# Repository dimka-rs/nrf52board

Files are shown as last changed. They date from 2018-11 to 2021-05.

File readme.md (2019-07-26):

# NRF52 + LoRa dev board

## Known issues
- Q1 footprint does not match any fets I have

## Components
- [NRF52 module E73-2G4M04S](https://www.aliexpress.com/item/32820692238.html) 
- [LoRa module RFM95W](https://www.aliexpress.com/item/32811523237.html)
- USB-UART CP2102
- LDO LP5907MFX-3.3
- LiPo charger MCP73831-2-OT

[See board pinout](pinout.md)

Board images:

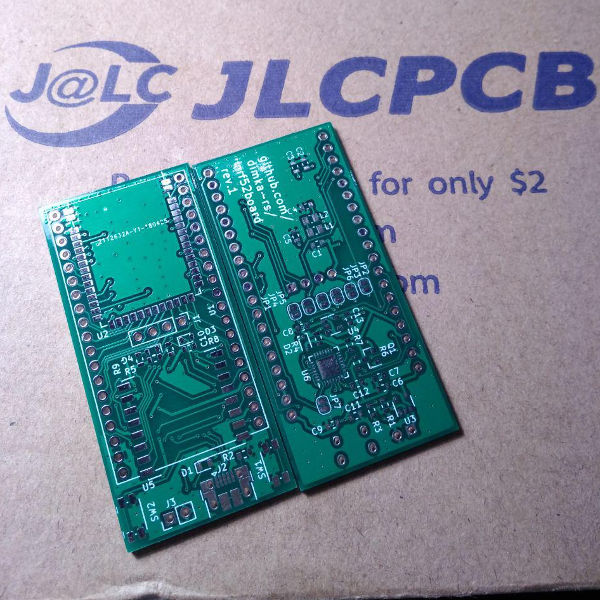
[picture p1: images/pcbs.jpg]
PCB Image

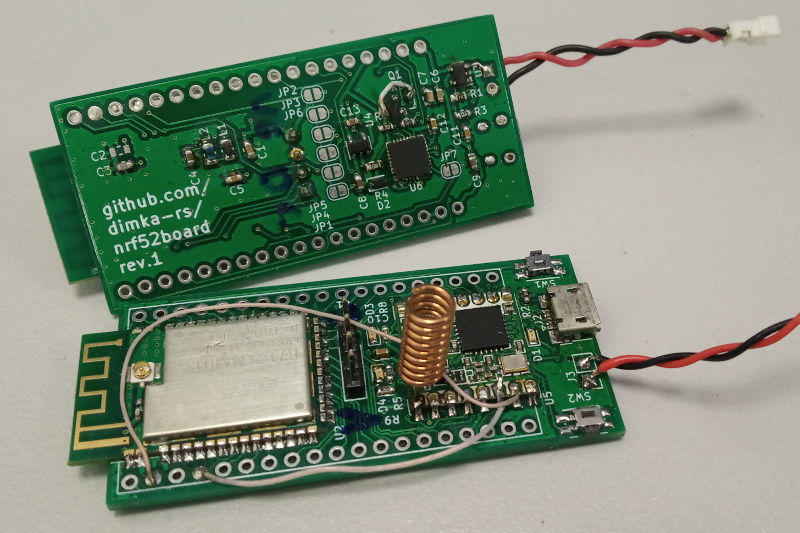
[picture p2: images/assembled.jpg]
Assembled boards


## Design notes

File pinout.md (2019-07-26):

# Board pinout

See tables below

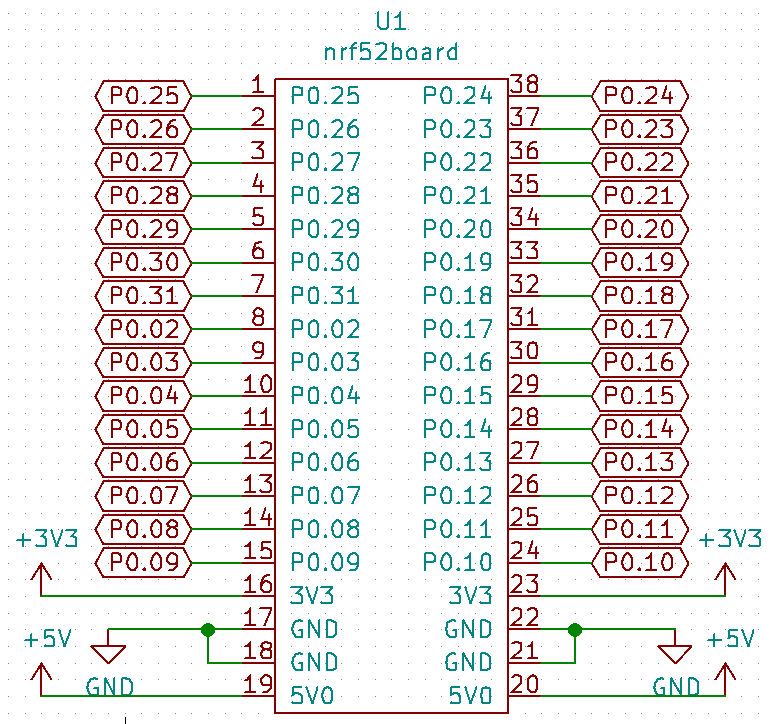
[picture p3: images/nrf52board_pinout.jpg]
pinout 1

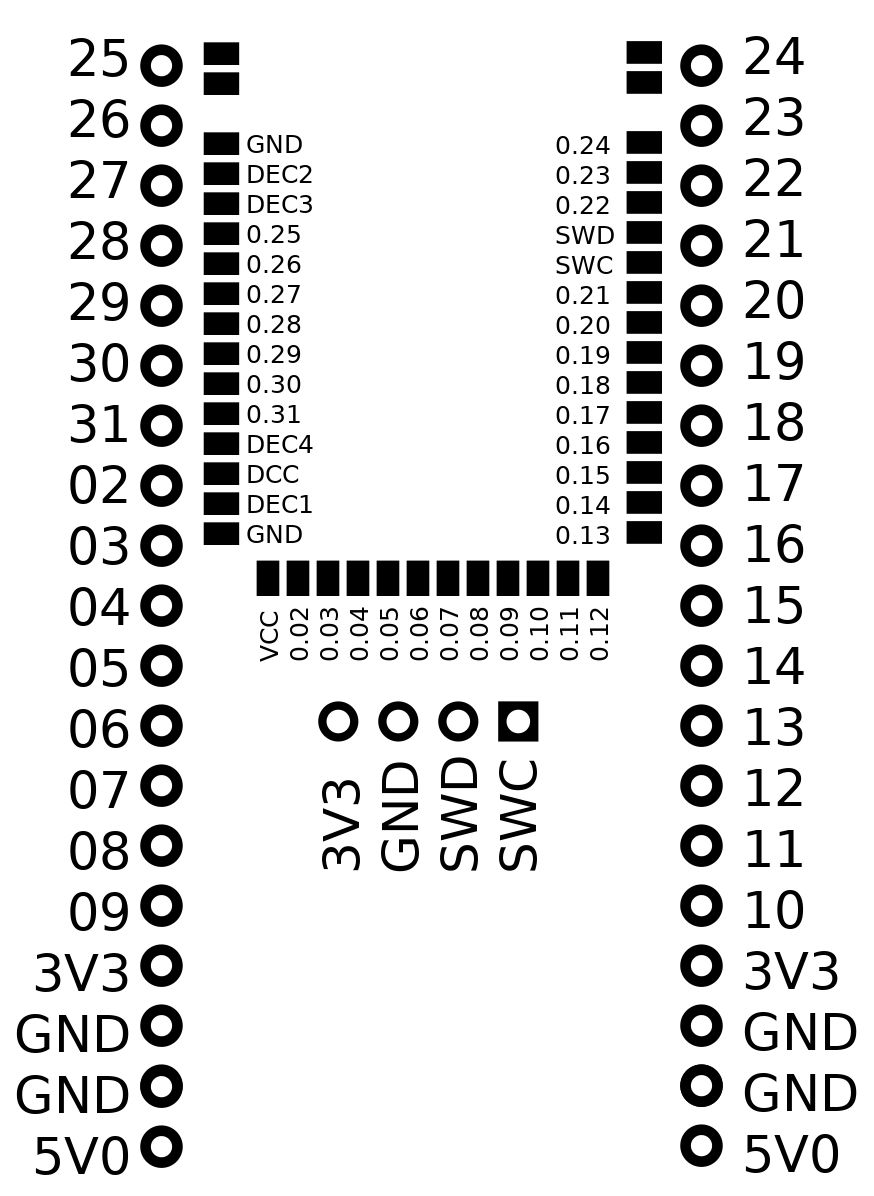
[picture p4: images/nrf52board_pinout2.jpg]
pinout 2


|pin|usage|alt fun|-|usage|alt fun|pin|
|---|-----|---|-|-----|---|---|
|  1|P0.25|SCK |-|P0.24|MISO | 38|
|  2|P0.26|RFM DIO|-|P0.23|MOSI | 37|
|  3|P0.27|RFM RST|-|P0.22|RMF nSS| 36|
|  4|P0.28| |-|P0.21|SW2/DTR| 35|
|  5|P0.29| |-|P0.20| | 34|
|  6|P0.30| |-|P0.19| | 33|
|  7|P0.31| |-|P0.18|D4 | 32|
|  8|P0.02| |-|P0.17|D3 | 31|
|  9|P0.03| |-|P0.16| | 30|
| 10|P0.04| |-|P0.15| | 29|
| 11|P0.05|NRF RTS|-|P0.14| | 28|
| 12|P0.06|NRF TXD|-|P0.13|SW1 | 27|
| 13|P0.07|NRF CTS|-|P0.12| | 26|
| 14|P0.08|NRF RXD|-|P0.11| | 25|
| 15|P0.09| |-|P0.10| | 24|
| 16|3V3  | |-|3V3  | | 23|
| 17|GND  | |-|GND  | | 22|
| 18|GND  | |-|GND  | | 21|
| 19|5V0  | |-|5V0  | | 20|

Programming header pinout
-------------------------

|pin|usage|
|---|-----|
|1|SWC|
|2|SWD|
|3|GND|
|4|3V3|

Module pinout
-------------

|Left|Central|Right|
|----|---|-----|
|0 GND|-|43 GND|
|1 GND|-|42 GND|
|-|-|-|
|2 GND|16 VCC|41 0.24|
|3 DEC2|17 0.02|40 0.23|
|4 DEC3|18 0.03|39 0.22|
|5 0.25|19 0.04|38 SWD|
|6 0.26|20 0.05|37 SWC|
|7 0.27|21 0.06|36 0.21|
|8 0.28|22 0.07|35 0.20|
|9 0.29|23 0.08|34 0.19|
|10 0.30|24 0.09|33 0.18|
|11 0.31|25 0.10|32 0.17|
|12 DEC4|26 0.11|31 0.16|
|13 DCC|27 0.12|30 0.15|
|14 DEC1|-|29 0.14|
|15 GND|-|28 0.13|

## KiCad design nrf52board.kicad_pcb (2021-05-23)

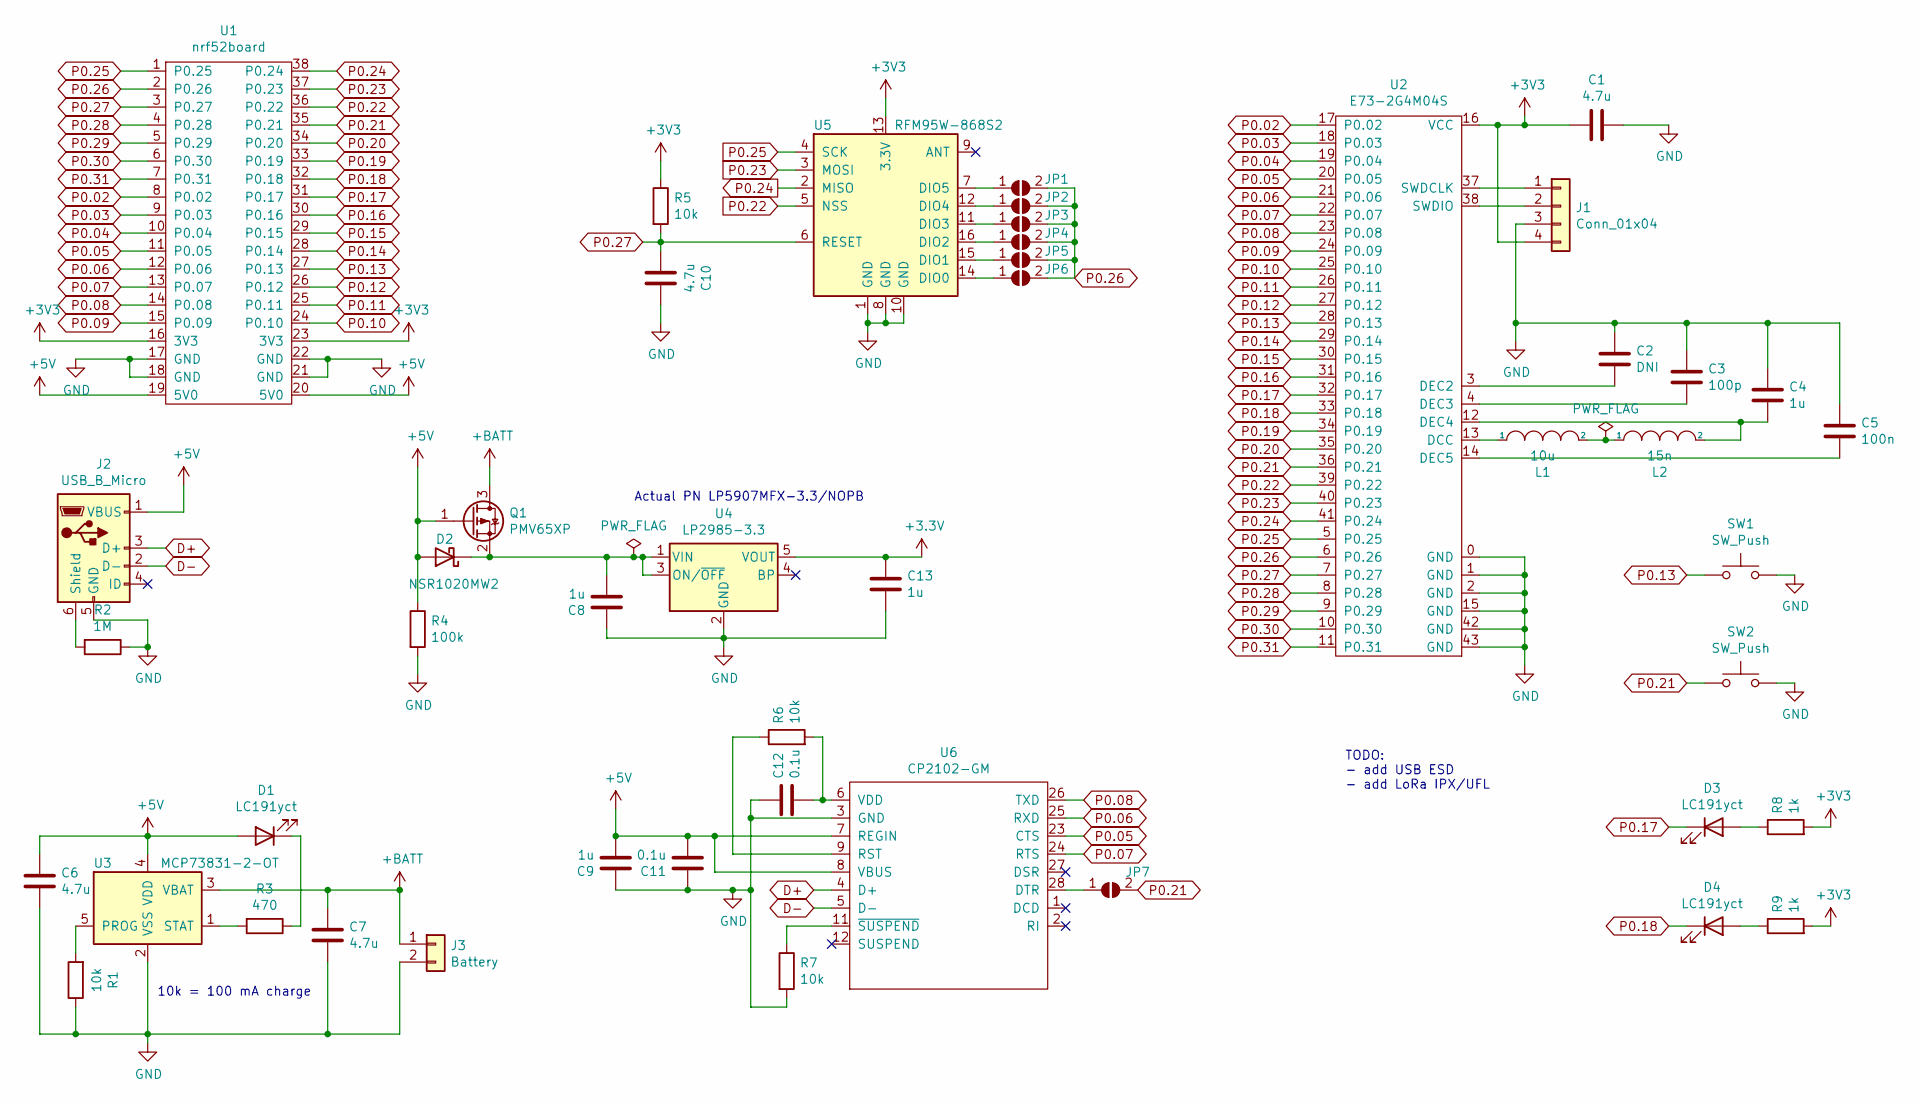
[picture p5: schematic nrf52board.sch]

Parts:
C1, C6, C7, C10: 4.7u; C_0603_1608Metric
C2: DNI; C_0603_1608Metric
C3: 100p; C_0603_1608Metric
C4, C8, C9, C13: 1u; C_0603_1608Metric
C5: 100n; C_0603_1608Metric
C11, C12: 0.1u; C_0603_1608Metric
D1, D3, D4: LC191yct; LED_0603_1608Metric
D2: NSR1020MW2; D_SOD-323
J1: Conn_01x04; PinHeader_1x04_P2.54mm_Vertical
J2: USB_B_Micro; USB_Micro-B_Amphenol_10103594-0001LF_Horizontal
J3: Battery; PinHeader_1x02_P2.54mm_Vertical
JP1, JP2, JP3, JP4, JP5, JP6, JP7: SolderJumper_2_Open; SolderJumper-2_P1.3mm_Open_RoundedPad1.0x1.5mm
L1: 10u; L_0805_2012Metric
L2: 15n; L_0805_2012Metric
Q1: PMV65XP; SOT-23
R1, R5, R6, R7: 10k; R_0603_1608Metric
R2: 1M; R_0603_1608Metric
R3: 470; R_0603_1608Metric
R4: 100k; R_0603_1608Metric
R8, R9: 1k; R_0603_1608Metric
SW1, SW2: SW_Push; Panasonic_EVQPUJ_EVQPUA
U1: nrf52board
U2: E73-2G4M04S
U3: MCP73831-2-OT; SOT-23-5
U4: LP2985-3.3; SOT-23-5
U5: RFM95W-868S2; Hopref_RFM9XW_SMD
U6: CP2102-GM; QFN-28-1EP_5x5mm_P0.5mm_EP3.35x3.35mm

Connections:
+5V: C6.1, C9.2, C11.2, D1.2 (A), D2.2 (A), J2.1 (VBUS), Q1.1 (G), R4.1, U1.19 (5V0), U1.20 (5V0), U3.4 (VDD), U6.7 (REGIN), U6.8 (VBUS)
+BATT: C7.1, J3.1, Q1.3 (D), U3.3 (VBAT)
D+: J2.3 (D+), U6.4 (D+)
D-: J2.2 (D-), U6.5 (D-)
GND: C1.1, C2.2, C3.2, C4.2, C5.2, C6.2, C7.2, C8.1, C9.1, C10.1, C11.1, C12.1, C13.2, J1.3, J2.5 (GND), J3.2, R1.1, R2.1, R4.2, R7.2, SW1.2, SW2.2, U1.17 (GND), U1.18 (GND), U1.21 (GND), U1.22 (GND), U2.0 (GND), U2.1 (GND), U2.2 (GND), U2.15 (GND), U2.42 (GND), U2.43 (GND), U3.2 (VSS), U4.2 (GND), U5.1 (GND), U5.8 (GND), U5.10 (GND), U6.3 (GND)
unnamed: C2.1, U2.3 (DEC2)
unnamed: C3.1, U2.4 (DEC3)
unnamed: C4.1, L2.2, U2.12 (DEC4)
unnamed: C5.1, U2.14 (DEC5)
unnamed: C8.2, D2.1 (K), Q1.2 (S), U4.1 (VIN), U4.3 (ON/~OFF~)
unnamed: C12.2, R6.2, U6.6 (VDD)
unnamed: D1.1 (K), R3.1
unnamed: D3.2 (A), R8.1
unnamed: D4.2 (A), R9.1
unnamed: J1.1, U2.37 (SWDCLK)
unnamed: J1.2, U2.38 (SWDIO)
unnamed: J2.6 (Shield), R2.2
unnamed: JP1.1 (A), U5.7 (DIO5)
unnamed: JP2.1 (A), U5.12 (DIO4)
unnamed: JP3.1 (A), U5.11 (DIO3)
unnamed: JP4.1 (A), U5.16 (DIO2)
unnamed: JP5.1 (A), U5.15 (DIO1)
unnamed: JP6.1 (A), U5.14 (DIO0)
unnamed: JP7.1 (A), U6.28 (DTR)
unnamed: L1.1, U2.13 (DCC)
unnamed: L1.2, L2.1
unnamed: R1.2, U3.5 (PROG)
unnamed: R3.2, U3.1 (STAT)
unnamed: R6.1, U6.9 (RST)
unnamed: R7.1, U6.11 (~SUSPEND)
P0.02: U1.8 (P0.02), U2.17 (P0.02)
P0.03: U1.9 (P0.03), U2.18 (P0.03)
P0.04: U1.10 (P0.04), U2.19 (P0.04)
P0.05: U1.11 (P0.05), U2.20 (P0.05), U6.23 (CTS)
P0.06: U1.12 (P0.06), U2.21 (P0.06), U6.25 (RXD)
P0.07: U1.13 (P0.07), U2.22 (P0.07), U6.24 (RTS)
P0.08: U1.14 (P0.08), U2.23 (P0.08), U6.26 (TXD)
P0.09: U1.15 (P0.09), U2.24 (P0.09)
P0.10: U1.24 (P0.10), U2.25 (P0.10)
P0.11: U1.25 (P0.11), U2.26 (P0.11)
P0.12: U1.26 (P0.12), U2.27 (P0.12)
P0.13: SW1.1, U1.27 (P0.13), U2.28 (P0.13)
P0.14: U1.28 (P0.14), U2.29 (P0.14)
P0.15: U1.29 (P0.15), U2.30 (P0.15)
P0.16: U1.30 (P0.16), U2.31 (P0.16)
P0.17: D3.1 (K), U1.31 (P0.17), U2.32 (P0.17)
P0.18: D4.1 (K), U1.32 (P0.18), U2.33 (P0.18)
P0.19: U1.33 (P0.19), U2.34 (P0.19)
P0.20: U1.34 (P0.20), U2.35 (P0.20)
P0.21: JP7.2 (B), SW2.1, U1.35 (P0.21), U2.36 (P0.21)
P0.22: U1.36 (P0.22), U2.39 (P0.22), U5.5 (NSS)
P0.23: U1.37 (P0.23), U2.40 (P0.23), U5.3 (MOSI)
P0.24: U1.38 (P0.24), U2.41 (P0.24), U5.2 (MISO)
P0.25: U1.1 (P0.25), U2.5 (P0.25), U5.4 (SCK)
P0.26: JP1.2 (B), JP2.2 (B), JP3.2 (B), JP4.2 (B), JP5.2 (B), JP6.2 (B), U1.2 (P0.26), U2.6 (P0.26)
P0.27: C10.2, R5.2, U1.3 (P0.27), U2.7 (P0.27), U5.6 (RESET)
P0.28: U1.4 (P0.28), U2.8 (P0.28)
P0.29: U1.5 (P0.29), U2.9 (P0.29)
P0.30: U1.6 (P0.30), U2.10 (P0.30)
P0.31: U1.7 (P0.31), U2.11 (P0.31)

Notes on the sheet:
Actual PN LP5907MFX-3.3/NOPB
TODO: - add USB ESD - add LoRa IPX/UFL
10k = 100 mA charge

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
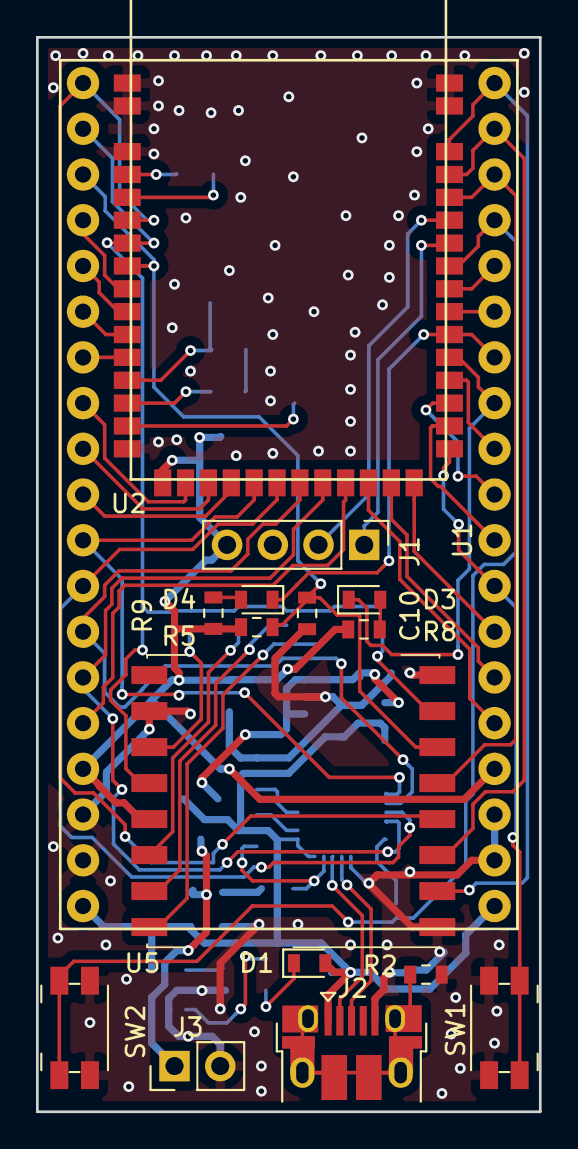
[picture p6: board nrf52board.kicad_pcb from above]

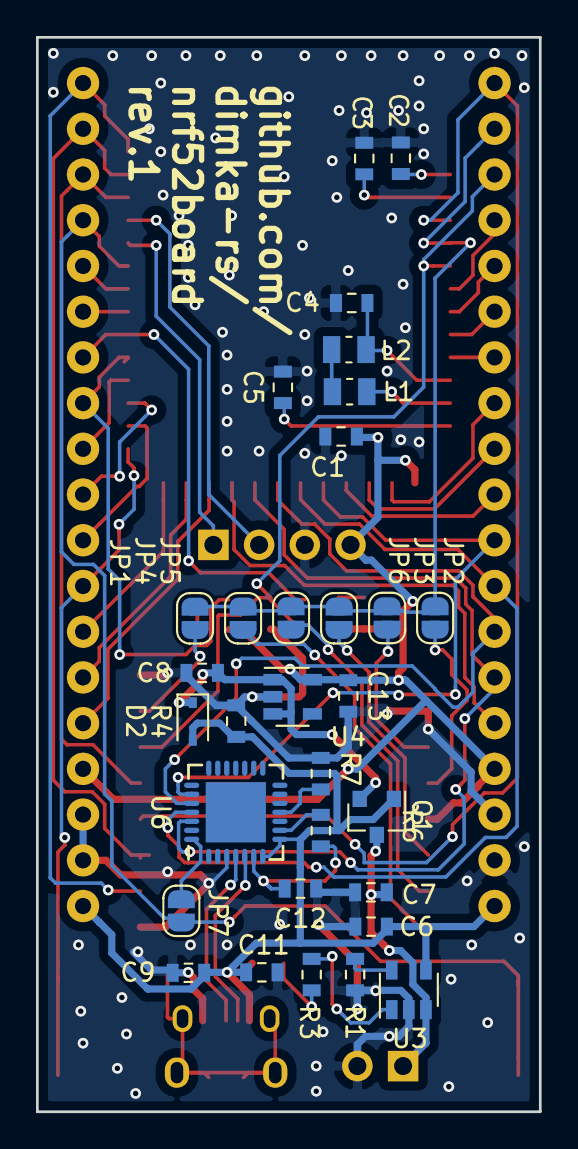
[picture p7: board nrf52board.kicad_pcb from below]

Board: 2 copper layers, 27.9 x 59.7 mm, 47 parts (31 on the bottom side), 61 nets.

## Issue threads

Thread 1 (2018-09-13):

HW: Wrong Q1 footprint, no labels for debug conn

dimka-rs, 2018-09-13:
* ~~Change Q1 footprint to some real life part like PMV65XP~~
* Add labels for J1
* Connect RFM95 GPIO to different E73 GPIO

dimka-rs, 2021-03-08:
Q1 fixed in 88ee510125b2624e2d1a86b95093e88c8737f010

Closed 2021-05-23.

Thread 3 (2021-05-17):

HW: Part Details Missing

jowami, 2021-05-17:
We have some questiones regarding the BOM and the design on KiCAD.
1) What is the part number of D2, SW1, SW2, Q1
2) What is the color of D1,D3,D4
3) What is the full part of E73-2G4M04S . There are E73-2G4M04S1A, E73-2G4M04S1D，E73-2G4M04S1AX etc.

dimka-rs, 2021-05-23:
Hi, @jowami
1. D2: NSR1020MW2; SW1,2: no idea, some side tact switch I had; Q1: PMV65XP.
2. D1,3,4: LC191yct. I have them all yellow, but you can use any 0603 LED you like.
3. My part is marked 2G4M04S. it is old, I guess naming has changed since. It is NRF52832, so E73-2G4M04S1B looks best fit.

jowami, 2021-05-24:
@dimka-rs Thanks, will submit the changes and send you a pull request

dimka-rs, 2021-05-26:
@jowami you're welcome. I've already pushed some changes.

jowami, 2021-05-26:
Thanks!

Could you please contact me on jwamicha@gmail.com

We have some work.

Thanks.

dimka-rs, 2021-05-26:
@jowami I've found and bushed button name. It is SKSCLCE010, but 'PTS840 GMP SMTR LFS' and 'EVQ-P7K01P' should also fit.

Closed 2021-05-24.

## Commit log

2018-03-10 added board symbol
    [nrf52board.sch]
2018-03-10 added simple pcb
    [_saved_nrf52board.sch]
2018-03-25 updated module foorptint
    [_saved_nrf52board.sch, nrf52board.kicad_pcb]
2018-04-01 moved libs to kicad-libs
    [nrf52board.sch]
2018-04-02 sch: added power
    [nrf52board.sch]
2018-04-08 charger done
    [nrf52board.sch]
2018-04-09 sch: update todo
    [nrf52board.sch]
2018-04-12 sch: updated TODO
    [nrf52board.sch]
2018-04-14 sch: added cp2102, lora connected
    [nrf52board.sch]
2018-04-17 sch: added one more btn and led
    [nrf52board.kicad_pcb, nrf52board.sch]
2018-04-17 pcb: half way through
    [nrf52board.kicad_pcb, nrf52board.sch]
2018-04-20 pcb: almost done
    [nrf52board.kicad_pcb]
2018-04-20 pcb: traciong done
    [nrf52board.kicad_pcb]
2018-04-20 pcb: done
    [nrf52board.kicad_pcb]
2018-04-24 gerbers created
    [nrf52board.kicad_pcb]
2018-04-26 gerbers created fix
    [nrf52board-B.Cu.gbl, nrf52board-B.Mask.gbs, nrf52board-B.SilkS.gbo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]
2019-07-22 add interactive bom
2019-07-22 add assembled board image
2019-07-26 sch: rescue
    [nrf52board.sch]
2021-03-08 Change Q1 to PMV65XP
    [nrf52board.sch]
2021-03-08 Update Q1 on PCB
    [nrf52board.kicad_pcb, nrf52board.sch]
2021-05-23 Fix BOM
    [nrf52board.kicad_pcb, nrf52board.sch]
2021-05-26 add button name
    [nrf52board.sch]
